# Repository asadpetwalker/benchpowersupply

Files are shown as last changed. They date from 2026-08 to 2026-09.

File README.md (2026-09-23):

# benchpowersupply

# What it is

A 500W Variable PSU with real time CC/CV error correction, current clamping, a 16 bit DAC for millivolt and milliamp precision. 

# Why I Made This
Precision power supplies are really cool, and high power power supplies are also really cool, some precision PSUs having milliamp/millivolt precision, and some high power PSUs going upto 2kW, but I couldn't find a single power supply with more than 300W with sub volt precision for under a lot of money, and I've always wanted to design one since they're really impressive, so I did. 

# Pictures









# BOM

| Item | Purpose | Qty | Cost | Link |
| :--- | :--- | :---: | :---: | :--- |
| **FC4L90R002FER** | CURRENT SENSE CHIP 1% 0.002 OHM | 5 | $13.75 | - |
| **8174** | TERM SCREW 10-32 4 PIN PCB | 4 | $5.56 | - |
| **FCR7350Y** | 4MM PANEL SKT S16N-PC YELLOW | 2 | $15.74 | - |
| **FCR7350B** | 4MM PANEL SKT S16N-PC BLACK | 2 | $15.32 | - |
| **INA238AQDGSRQ1** | IC PWR MONITOR 10VSSOP | 2 | $9.00 | - |
| **411019-01** | CORD 14AWG NEMA 5-15P TO CBL 10' | 2 | $35.12 | - |
| **0190700090** | CONN RING CIRC 14-16AWG #10 | 6 | $1.32 | - |
| **LM5149RGYR** | 800mV~55V Adjustable Step-down DC DC Controller | 2 | $7.96 | [LCSC](https://www.lcsc.com/product-detail/C7528454.html) |
| **LM5164DDAR** | 1MHz Step-down Adjustable 1A Voltage Regulator | 2 | $0.00 | [LCSC](https://www.lcsc.com/product-detail/C477928.html) |
| **ESP32-S3-WROOM-1-N4** | 2.4GHz ESP32-S3 On-board PCB Antenna Module | 2 | $8.30 | [LCSC](https://www.lcsc.com/product-detail/C2913197.html) |
| **ADS8681IRUMR** | SPI 4.75V~5.25V WQFN-16 Analog to Digital Converter | 2 | $19.80 | [LCSC](https://www.lcsc.com/product-detail/C2670107.html) |
| **REF6025IDGKR** | Series Voltage Reference IC Fixed 2.5V ±0.05% | 2 | $11.72 | [LCSC](https://www.lcsc.com/product-detail/C2157015.html) |
| **DAC8562SDGSR** | 10us 2.7V~5.5V Digital to Analog Converter | 2 | $21.98 | [LCSC](https://www.lcsc.com/product-detail/C127965.html) |
| **INA241A4IDR** | -5V~110V 100V/V Instrumentation / Current Sense Amp | 2 | $7.11 | [LCSC](https://www.lcsc.com/product-detail/C22427873.html) |
| **TLV3501AIDR** | Rail-to-Rail Input/Output SOP-8 Comparator | 2 | $7.00 | [LCSC](https://www.lcsc.com/product-detail/C43484.html) |
| **SER2915H-223KL** | 30A 22uH ±10% Shielded Inductor SMD | 2 | $17.71 | [LCSC](https://www.lcsc.com/product-detail/C19276066.html) |
| **BSC027N10NS5** | N-Channel 100V 3W Surface Mount MOSFET | 2 | $9.80 | [LCSC](https://www.lcsc.com/product-detail/C534315.html) |
| **BSC040N10NS5** | 100V 86A 139W Surface Mount MOSFET | 2 | $1.96 | [LCSC](https://www.lcsc.com/product-detail/C534334.html) |
| **AP2112K-3.3TRG1** | 3.3V Positive Fixed LDO Regulator (TECH PUBLIC) | 5 | $0.00 | [LCSC](https://www.lcsc.com/product-detail/C23380830.html) |
| **AP2112K-3.3TRG1** | 3.3V Positive Fixed LDO Regulator (DIODES) | 5 | $0.00 | [LCSC](https://www.lcsc.com/product-detail/C51118.html) |
| **CC0805KRX7R9BB104** | 100nF ±10% 50V Ceramic Capacitor X7R 0805 | 20 | $0.39 | [LCSC](https://www.lcsc.com/product-detail/C49678.html) |
| **CL21B104KBCNNNC** | 100nF ±10% 50V Ceramic Capacitor X7R 0805 | 20 | $0.30 | [LCSC](https://www.lcsc.com/product-detail/C1711.html) |
| **CL21B105KBFNNNE** | 1uF ±10% 50V Ceramic Capacitor X7R 0805 | 20 | $0.81 | [LCSC](https://www.lcsc.com/product-detail/C28323.html) |
| **0805B222K500NT** | 2.2nF ±10% 50V Ceramic Capacitor X7R 0805 | 20 | $0.12 | [LCSC](https://www.lcsc.com/product-detail/C36576.html) |
| **CC0805JRNPO9BN560** | 56pF ±5% 50V Ceramic Capacitor NP0 0805 | 50 | $0.66 | [LCSC](https://www.lcsc.com/product-detail/C113831.html) |
| **HGC0805R5475K500NSLJ** | 4.7uF ±10% 50V Ceramic Capacitor X5R 0805 | 10 | $0.49 | [LCSC](https://www.lcsc.com/product-detail/C7472969.html) |
| **CL21A106KAYNNNE** | 10uF ±10% 25V Ceramic Capacitor X5R 0805 | 20 | $1.60 | [LCSC](https://www.lcsc.com/product-detail/C15850.html) |
| **0805CG101J500NT** | 100pF ±5% 50V Ceramic Capacitor C0G 0805 | 50 | $0.48 | [LCSC](https://www.lcsc.com/product-detail/C82028.html) |
| **HGC0805R5476M100NSLJ** | 47uF ±20% 10V Ceramic Capacitor X5R 0805 | 5 | $0.81 | [LCSC](https://www.lcsc.com/product-detail/C19103846.html) |
| **1210B104K251CT** | 100nF ±10% 250V Ceramic Capacitor X7R 1210 | 10 | $0.59 | [LCSC](https://www.lcsc.com/product-detail/C304007.html) |
| **EFVH100ADA101M10C0** | 100uF ±20% 100V Aluminum Electrolytic Capacitor | 5 | $1.15 | [LCSC](https://www.lcsc.com/product-detail/C22387799.html) |
| **CL21B102KBCNNNC** | 1nF ±10% 50V Ceramic Capacitor X7R 0805 | 20 | $0.30 | [LCSC](https://www.lcsc.com/product-detail/C46653.html) |
| **2N7002** | N-Channel 60V 115mA 200mW MOSFET SOT-23 | 50 | $0.56 | [LCSC](https://www.lcsc.com/product-detail/C916396.html) |
| **FRC0603F8872TS** | 88.7kΩ ±1% 100mW 0603 Thick Film Resistor | 100 | $0.27 | [LCSC](https://www.lcsc.com/product-detail/C2999456.html) |
| **FRC0603F1072TS** | 10.7kΩ ±1% 100mW 0603 Thick Film Resistor | 100 | $0.23 | [LCSC](https://www.lcsc.com/product-detail/C5153968.html) |
| **RC0603FR-07100KL** | 100kΩ ±1% 100mW 0603 Thick Film Resistor | 100 | $0.23 | [LCSC](https://www.lcsc.com/product-detail/C14675.html) |
| **FRC0603F3163TS** | 316kΩ ±1% 100mW 0603 Thick Film Resistor | 100 | $0.23 | [LCSC](https://www.lcsc.com/product-detail/C2998125.html) |
| **FRC0603F4703TS** | 470kΩ ±1% 100mW 0603 Thick Film Resistor | 100 | $0.21 | [LCSC](https://www.lcsc.com/product-detail/C2907040.html) |
| **HoJLR2512-3W-5mR-1%** | 5mΩ 3W Current Sense Resistor ±1% 2512 | 5 | $0.45 | [LCSC](https://www.lcsc.com/product-detail/C2903482.html) |
| **FRC0603F6193TS** | 619kΩ ±1% 100mW 0603 Thick Film Resistor | 100 | $0.13 | [LCSC](https://www.lcsc.com/product-detail/C5713292.html) |
| **RC0603FR-0710KL** | 10kΩ ±1% 100mW 0603 Thick Film Resistor | 100 | $0.35 | [LCSC](https://www.lcsc.com/product-detail/C98220.html) |
| **FRC0603F1502TS** | 15kΩ ±1% 100mW 0603 Thick Film Resistor | 100 | $0.22 | [LCSC](https://www.lcsc.com/product-detail/C2906995.html) |
| **AR05BTCW4003** | 400kΩ ±0.1% 125mW 0805 Thin Film Resistor | 20 | $0.94 | [LCSC](https://www.lcsc.com/product-detail/C3013969.html) |
| **FRC0603J102 TS** | 1kΩ ±5% 100mW 0603 Thick Film Resistor | 100 | $0.24 | [LCSC](https://www.lcsc.com/product-detail/C2907113.html) |
| **FRC0603J472 TS** | 4.7kΩ ±5% 100mW 0603 Thick Film Resistor | 100 | $0.21 | [LCSC](https://www.lcsc.com/product-detail/C2907166.html) |
| **RS-03K2701FT** | 2.7kΩ ±1% 100mW 0603 Thick Film Resistor | 100 | $0.20 | [LCSC](https://www.lcsc.com/product-detail/C118394.html) |
| **HRC0603F5101ENTN** | 5.1kΩ ±1% 100mW 0603 Thick Film Resistor | 100 | $0.12 | [LCSC](https://www.lcsc.com/product-detail/C54920932.html) |
| **1RC0603J0101** | 100Ω ±5% 100mW 0603 Thick Film Resistor | 100 | $0.17 | [LCSC](https://www.lcsc.com/product-detail/C54531636.html) |
| **EC11E15244B2** | Through Hole Encoder | 4 | $9.59 | [LCSC](https://www.lcsc.com/product-detail/C470754.html) |
| **SMMS0650-680M** | 1.5A 68uH ±20% Molded Inductor SMD | 5 | $0.89 | [LCSC](https://www.lcsc.com/product-detail/C2894721.html) |
| **SMPS** | 600W 60V SMPS PSU | 1 | 31.99 | [Amazon](https://www.amazon.com/NUOWEIDE-Converter-Transformer-Controller-Electric/dp/B0FTYPPZPR/ref=sr_1_5?sr=8-5)

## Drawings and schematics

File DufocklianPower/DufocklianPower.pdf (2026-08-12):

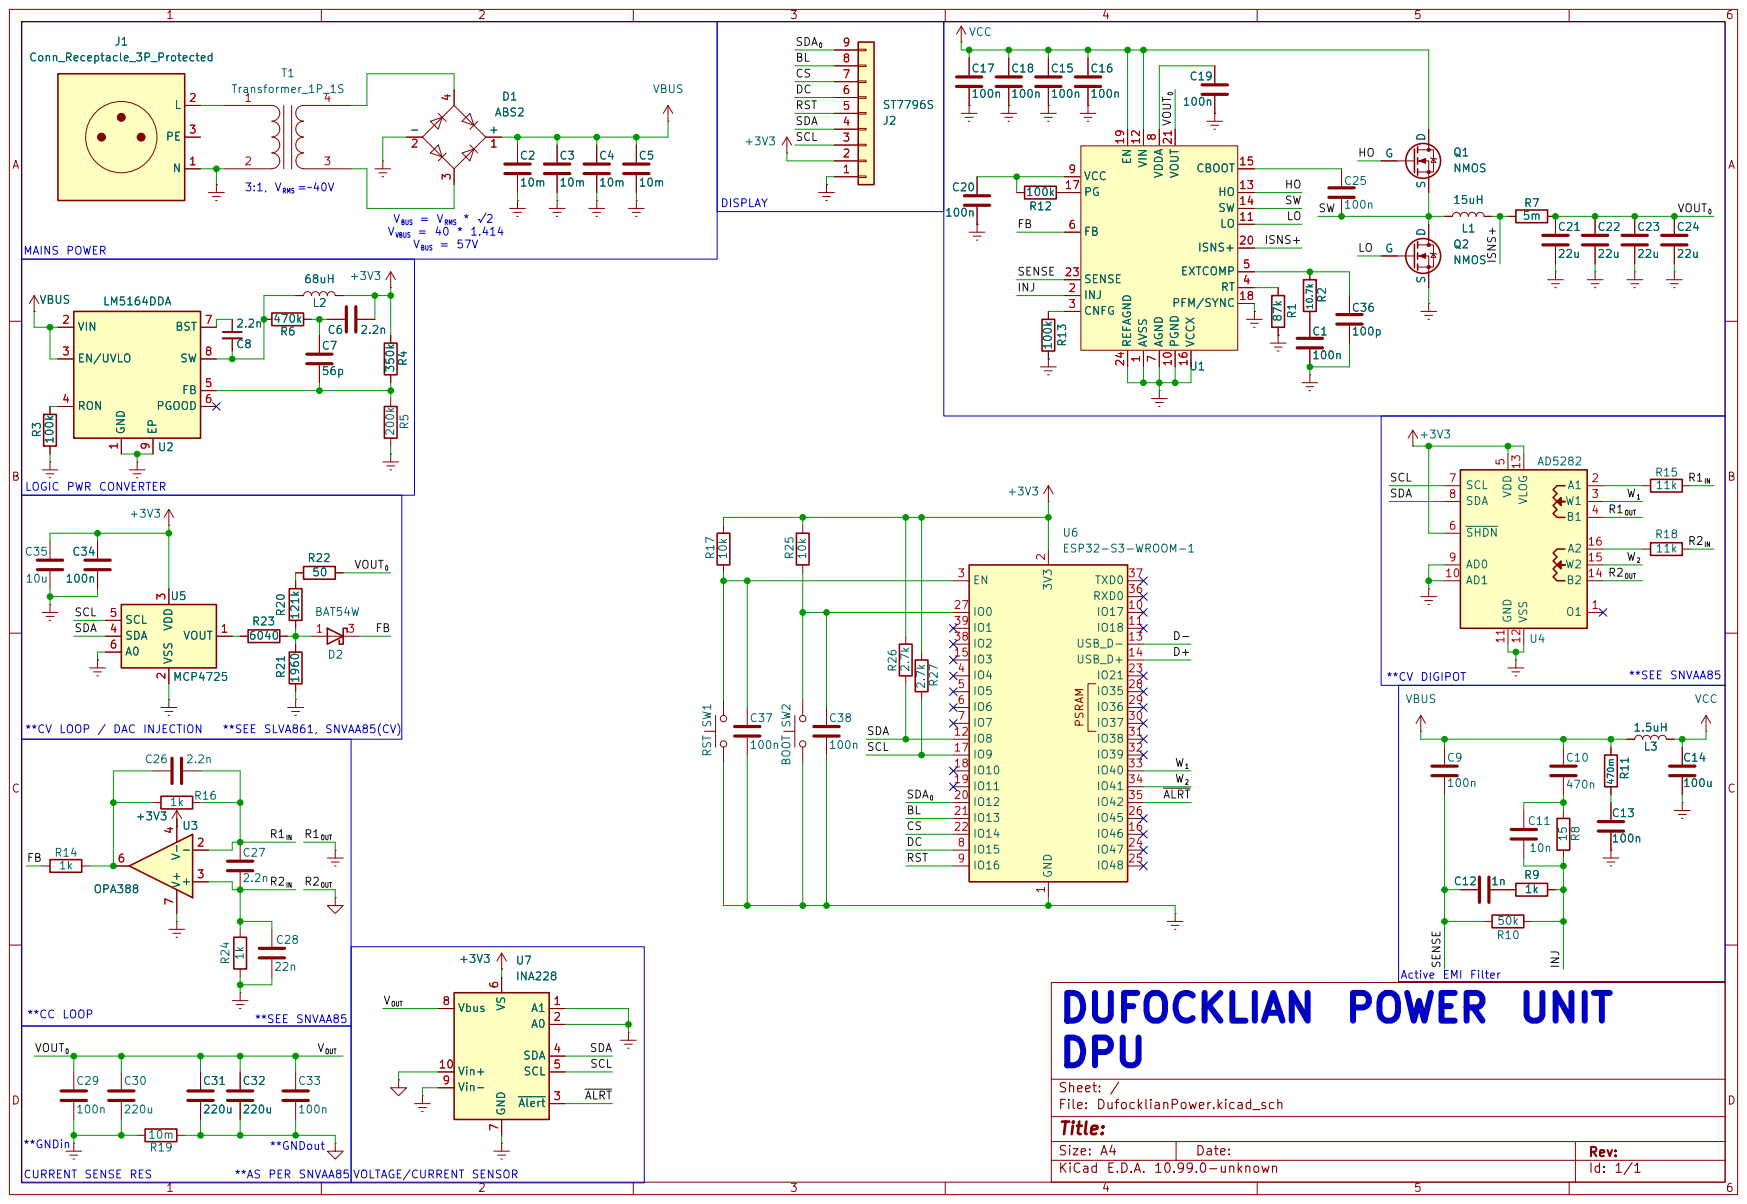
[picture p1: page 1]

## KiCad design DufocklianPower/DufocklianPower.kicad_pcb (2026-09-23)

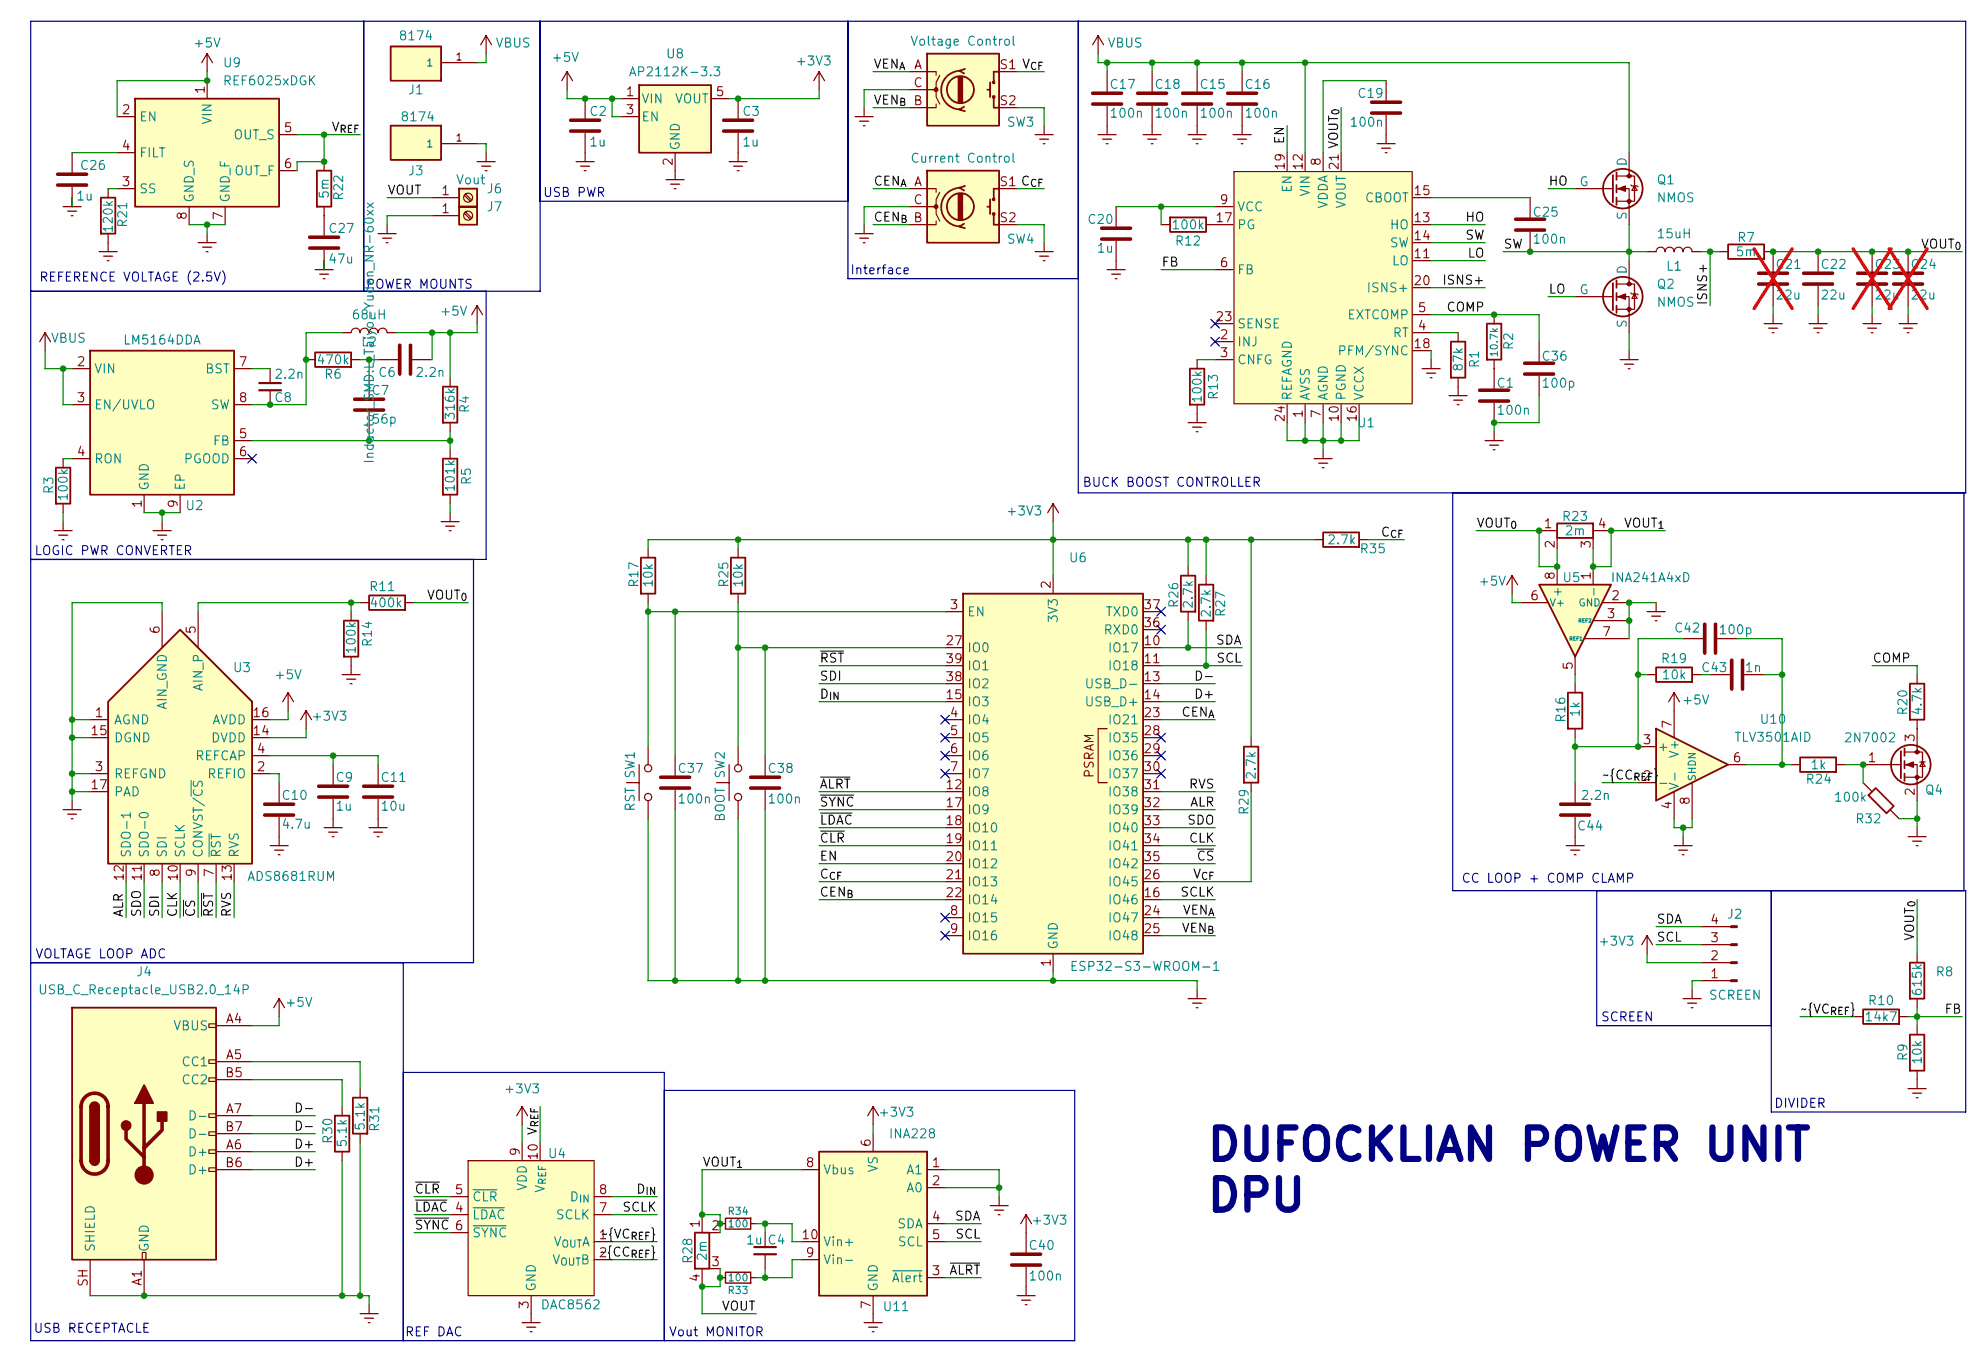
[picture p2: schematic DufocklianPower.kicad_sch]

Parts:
C1, C19, C25, C37, C38, C40: 100n; C_0805_2012Metric
C2, C3, C4, C9, C20, C26: 1u; C_0805_2012Metric
C6, C8, C44: 2.2n; C_0805_2012Metric
C7: 56p; C_0805_2012Metric
C10: 4.7u; C_0805_2012Metric
C11: 10u; C_0805_2012Metric
C15, C16, C17, C18: 100n; C_1210_3225Metric
C21: 22u; C_Elec_10x10.2; not fitted
C22: 22u; C_Elec_10x10.2
C23, C24: 22u; C_2220_5750Metric; not fitted
C27: 47u; C_0805_2012Metric
C36, C42: 100p; C_0805_2012Metric
C43: 1n; C_0805_2012Metric
J1, J3: 8174; KEYSTONE_8174; PARTREV B
J2: SCREEN; PinHeader_1x04_P2.54mm_Vertical
J4: USB_C_Receptacle_USB2.0_14P; USB_C_Receptacle_GCT_USB4105-xx-A_16P_TopMnt_Horizontal
J6: Vout; Banana_Cliff_FCR7350Y_S16N-PC_Horizontal
J7: Screw_Terminal_01x01; Banana_Cliff_FCR7350Y_S16N-PC_Horizontal
L1: 15uH; IND_SER2915H-223KL
L2: 68uH; L_Taiyo-Yuden_NR-60xx
Q1, Q2: NMOS; TRANS_BSC027N10NS5ATMA1
Q4: 2N7002; SOT-23
R1: 87k; R_0603_1608Metric
R2: 10.7k; R_0603_1608Metric
R3, R12, R13, R14, R32: 100k; R_0603_1608Metric
R4: 316k; R_0603_1608Metric
R5: 101k; R_0603_1608Metric
R6: 470k; R_0603_1608Metric
R7: 5m; R_2512_6332Metric
R8: 615k; R_0603_1608Metric
R9, R17, R19, R25: 10k; R_0603_1608Metric
R10: 14k7; R_0603_1608Metric
R11: 400k; R_0805_2012Metric
R16, R24: 1k; R_0603_1608Metric
R20: 4.7k; R_0603_1608Metric
R21: 120k; R_0603_1608Metric
R22: 5m; R_0603_1608Metric
R23, R28: 2m; FC4L90_OHM
R26, R27, R29, R35: 2.7k; R_0603_1608Metric
R30, R31: 5.1k; R_0603_1608Metric
R33, R34: 100; R_0603_1608Metric
SW1: RST; SW_Push_1P1T-SH_NO_CK_KMR2xxG
SW2: BOOT; SW_Push_1P1T-SH_NO_CK_KMR2xxG
SW3: Voltage Control; RotaryEncoder_Alps_EC11E-Switch_Vertical_H20mm
SW4: Current Control; RotaryEncoder_Alps_EC11E-Switch_Vertical_H20mm
U1: VQFN24_RGY_TEX
U2: LM5164DDA; HSOP-8-1EP_3.9x4.9mm_P1.27mm_EP2.41x3.1mm_ThermalVias
U3: ADS8681RUM; QFN-16-1EP_4x4mm_P0.65mm_EP2.7x2.7mm
U4: DAC8562; TSSOP-10_3x3mm_P0.5mm
U5: INA241A4xD; SOIC-8_3.9x4.9mm_P1.27mm
U6: ESP32-S3-WROOM-1
U8: AP2112K-3.3; SOT-23-5
U9: REF6025xDGK; VSSOP-8_3x3mm_P0.65mm
U10: TLV3501AID; SOIC-8_3.9x4.9mm_P1.27mm
U11: INA228; TSSOP-10_3x3mm_P0.5mm

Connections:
+5V: C2.1, C6.2, J4.A4 (VBUS), J4.A9 (VBUS), J4.B4 (VBUS), J4.B9 (VBUS), L2.2, R4.1, U3.16 (AVDD), U5.6 (V+), U8.1 (VIN), U8.3 (EN), U9.1 (VIN), U9.2 (EN), U10.7 (V+)
/ALR: U3.12 (SDO-1), U6.32 (IO39)
/CEN_{A}: SW4.A, U6.23 (IO21)
/CEN_{B}: SW4.B, U6.22 (IO14)
/CLK: U3.10 (SCLK), U6.34 (IO41)
/COMP: C36.1, R2.1, R20.1, U1.5 (EXTCOMP)
/C_{CF}: R35.2, SW4.S1, U6.21 (IO13)
/D+: J4.A6 (D+), J4.B6 (D+), U6.14 (USB_D+)
/D-: J4.A7 (D-), J4.B7 (D-), U6.13 (USB_D-)
/D_{IN}: U4.8 (D_{IN}), U6.15 (IO3)
/EN: U1.19 (EN), U6.20 (IO12)
/FB: R8.2, R9.1, R10.2, U1.6 (FB)
/HO: Q1.2 (G), U1.13 (HO)
/ISNS+: L1.2, R7.1, U1.20 (ISNS+)
/LO: Q2.2 (G), U1.11 (LO)
/RVS: U3.13 (RVS), U6.31 (IO38)
/SCL: J2.3, R27.2, U6.11 (IO18), U11.5 (SCL)
/SCLK: U4.7 (SCLK), U6.16 (IO46)
/SDI: U3.8 (SDI), U6.38 (IO2)
/SDO: U3.11 (SDO-0), U6.33 (IO40)
/SW: C25.2, L1.1, Q1.3 (S), Q2.1 (D), U1.14 (SW)
/VEN_{A}: SW3.A, U6.24 (IO47)
/VEN_{B}: SW3.B, U6.25 (IO48)
/VOUT: J6.1 (Pin_1_1), R28.3, R28.4, R33.2
/VOUT_{0}: C21.1, C22.1, C23.1, C24.1, R7.2, R8.1, R11.2, R23.1, R23.2, U1.21 (VOUT), U5.8 (+)
/VOUT_{1}: R23.3, R23.4, R28.1, R28.2, R34.2, U5.1 (-), U11.8 (Vbus)
/V_{CF}: R29.2, SW3.S1, U6.26 (IO45)
/V_{REF}: R22.1, U4.10 (V_{REF}), U9.5 (OUT_S), U9.6 (OUT_F)
/~ALRT: U6.12 (IO8), U11.3 (~Alert)
/~CC_{REF}: U4.2 (V_{OUT}B), U10.2 (-)
/~CLR: U4.5 (~CLR), U6.19 (IO11)
/~CS: U3.9 (CONVST/~CS), U6.35 (IO42)
/~LDAC: U4.4 (~LDAC), U6.18 (IO10)
/~RST: U3.7 (~RST), U6.39 (IO1)
/~SYNC: U4.6 (~SYNC), U6.17 (IO9)
/~VC_{REF}: R10.1, U4.1 (V_{OUT}A)
GNDREF: C1.2, C2.2, C3.2, C9.1, C10.1, C11.1, C15.2, C16.2, C17.2, C18.2, C19.2, C20.2, C21.2, C22.2, C23.2, C24.2, C26.2, C27.2, C36.2, C37.2, C38.2, C40.2, C44.1, J2.1, J3.1, J3.2 (1__1), J3.3 (1__2), J3.4 (1__3), J4.A1 (GND), J4.A12 (GND), J4.B1 (GND), J4.B12 (GND), J4.SH (SHIELD), J7.1 (Pin_1_1), Q2.3 (S), Q4.2 (S), R1.2, R3.2, R5.2, R9.2, R13.2, R14.2, R21.2, R30.1, R31.2, R32.2, SW1.1, SW2.1, SW3.C, SW3.S2, SW4.C, SW4.S2, U1.1 (AVSS), U1.7 (AGND), U1.10 (PGND), U1.16 (VCCX), U1.18 (PFM/SYNC), U1.24 (REFAGND), U1.25 (GND), U2.1 (GND), U2.9 (EP), U3.1 (AGND), U3.3 (REFGND), U3.6 (AIN_GND), U3.15 (DGND), U3.17 (PAD), U4.3 (GND), U5.2 (GND), U5.3 (REF2), U5.4 (GND), U5.7 (REF1), U6.1 (GND), U6.40 (GND), U6.41 (GND), U8.2 (GND), U9.7 (GND_F), U9.8 (GND_S), U10.4 (V-), U10.8 (SHDN), U11.1 (A1), U11.2 (A0), U11.7 (GND)
unnamed: C1.1, R2.2
unnamed: C6.1, C7.2, R6.2
unnamed: C27.1, R22.2
unnamed: C42.2, C43.2, R24.1, U10.6
unnamed: C43.1, R19.2
unnamed: J4.A5 (CC1), R31.1
unnamed: J4.B5 (CC2), R30.2
unnamed: Q4.3 (D), R20.2
unnamed: Q4.1 (G), R24.2, R32.1
unnamed: R16.1, U5.5
unnamed: C25.1, U1.15 (CBOOT)
unnamed: R13.1, U1.3 (CNFG)
unnamed: R12.1, U1.17 (PG)
unnamed: R1.1, U1.4 (RT)
unnamed: C20.1, R12.2, U1.9 (VCC)
unnamed: C19.1, U1.8 (VDDA)
unnamed: C8.1, U2.7 (BST)
unnamed: C7.1, R4.2, R5.1, U2.5 (FB)
unnamed: R3.1, U2.4 (RON)
unnamed: C8.2, L2.1, R6.1, U2.8 (SW)
unnamed: R11.1, R14.1, U3.5 (AIN_P)
unnamed: C9.2, C11.2, U3.4 (REFCAP)
unnamed: C10.2, U3.2 (REFIO)
unnamed: C37.1, R17.2, SW1.2, U6.3 (EN)
unnamed: C38.1, R25.2, SW2.2, U6.27 (IO0)
unnamed: C26.1, U9.4 (FILT)
unnamed: R21.1, U9.3 (SS)
unnamed: C42.1, C44.2, R16.2, R19.1, U10.3 (+)
unnamed: C4.1, R34.1, U11.10 (Vin+)
unnamed: C4.2, R33.1, U11.9 (Vin-)
VBUS: C15.1, C16.1, C17.1, C18.1, J1.1, J1.2 (1__1), J1.3 (1__2), J1.4 (1__3), Q1.1 (D), U1.12 (VIN), U2.2 (VIN), U2.3 (EN/UVLO)

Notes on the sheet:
CC LOOP + COMP CLAMP
POWER MOUNTS
VOLTAGE LOOP ADC
Vout MONITOR
REFERENCE VOLTAGE (2.5V)
LOGIC PWR CONVERTER
SCREEN
DUFOCKLIAN POWER UNIT DPU
Interface
REF DAC
USB PWR
BUCK BOOST CONTROLLER
USB RECEPTACLE
DIVIDER

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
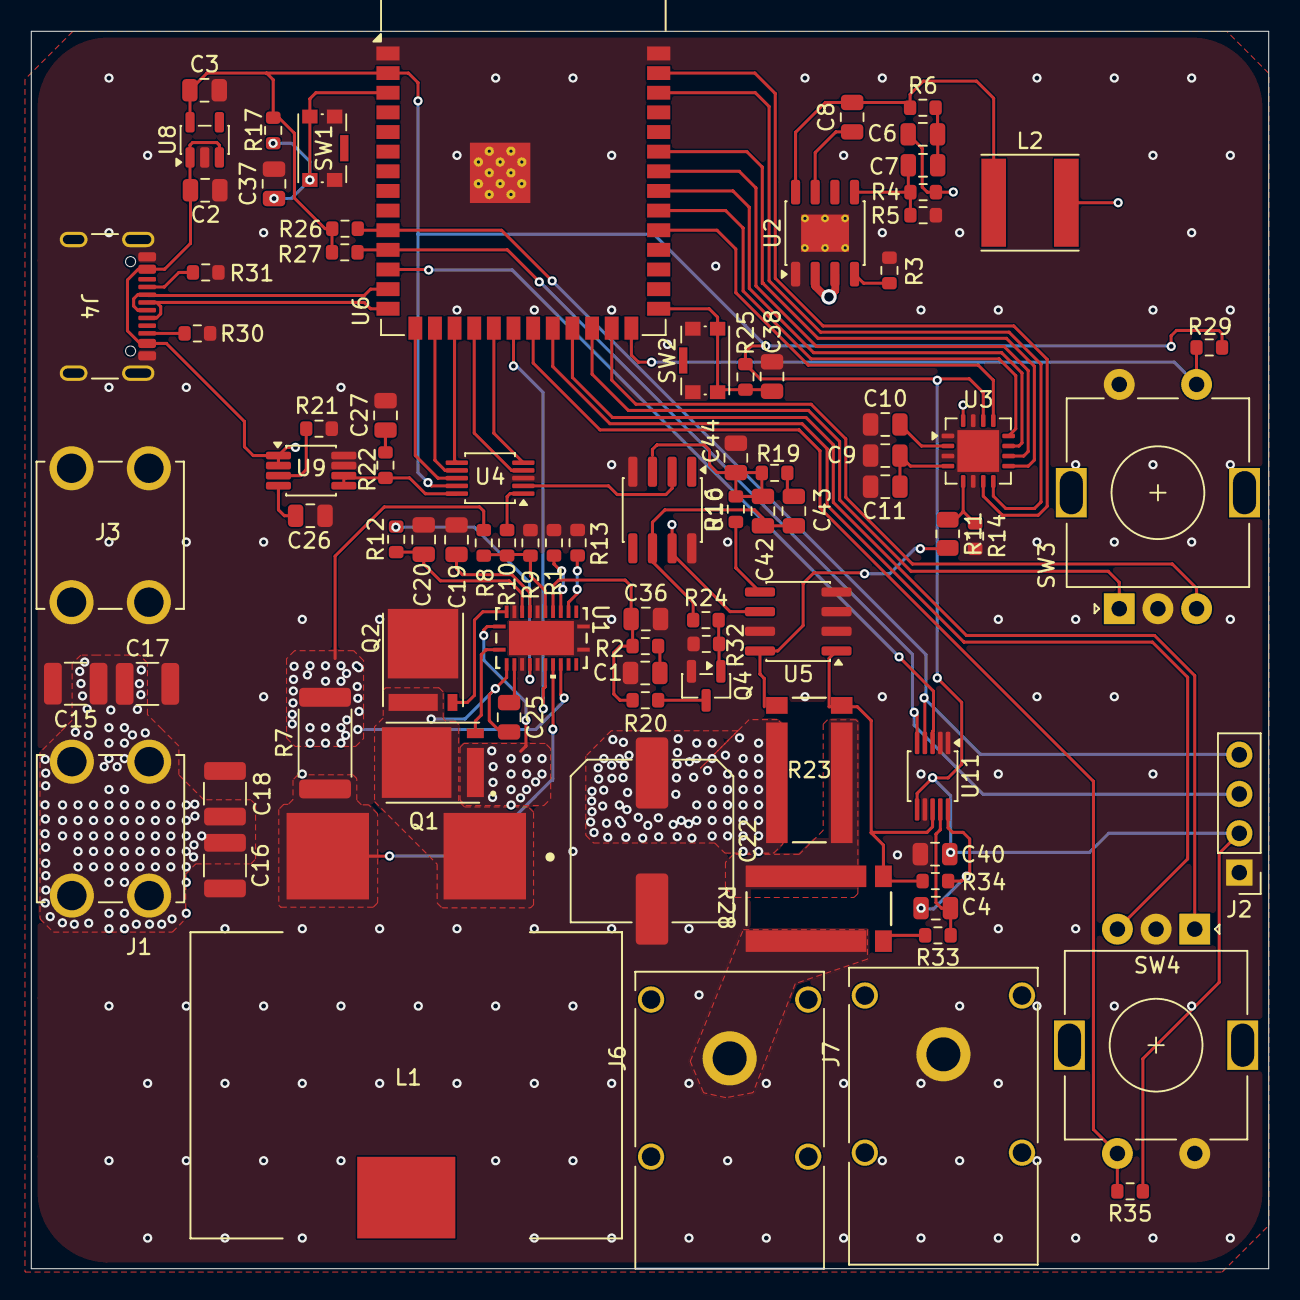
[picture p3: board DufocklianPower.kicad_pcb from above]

Board: 4 copper layers, 80.0 x 80.0 mm, 85 parts (0 on the bottom side), 70 nets.

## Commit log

2026-08-12 finished schematic (?)
    [DufocklianPower.kicad_pcb, DufocklianPower.kicad_sch]
2026-08-12 plotted again
    [DufocklianPower.kicad_sch]
2026-09-20 finish pcb
    [DufocklianPower.kicad_pcb, DufocklianPower.kicad_sch]
2026-09-20 finish via + change ind
    [DufocklianPower.kicad_pcb, DufocklianPower.kicad_sch]
2026-09-20 less drc
    [DufocklianPower.kicad_pcb]
2026-09-23 Finished BOM
